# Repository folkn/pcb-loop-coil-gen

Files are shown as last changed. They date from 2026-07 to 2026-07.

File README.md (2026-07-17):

# pcb-loop-coil-gen

Generates a parametric, multi-segment, capacitor-loaded loop-antenna PCB in KiCad — entirely
through the KiCad IPC API ([kicad-python](https://gitlab.com/kicad/code/kicad-python) / `kipy`).
PCB editor only; no schematic is involved.

It draws a ring of copper trace segments around a large center hole, bridges the gaps between
segments with parallel capacitor sets, and feeds the loop through an edge-mount SMA connector.
The board outline is a donut with a rectangular tab at the feed that borders the SMA connector.

## Requirements

- KiCad 10.x with the IPC API server enabled (Preferences > Plugins > Enable KiCad API)
- Python 3.9+ and [kicad-python](https://gitlab.com/kicad/code/kicad-python) built against your
  KiCad install (see kicad-python's own `COMPILING.md`)
- The four footprints under `libraries/` are already included (`.kicad_mod` files) — two custom
  hand-made parts, a Knowles part, and KiCad's stock trimmer capacitor copied out locally

## Usage

1. Open `project/loop_coil.kicad_pcb` in KiCad's PCB editor (or any blank `.kicad_pcb`), with the
   IPC API server running.
2. Edit the parameters at the top of `generate_loop_coil.py` (hole diameter, trace width, number
   of segments, which capacitors to place, SMA orientation, etc).
3. Run it against the open board:
   ```sh
   python generate_loop_coil.py
   ```
   This edits the currently open board in place as a single undo step. It does not save the file
   itself — save from the GUI (Ctrl+S) or call `board.save()` yourself.

If re-running against a board that already has a previous generation on it, clear it first:
```python
from kipy import KiCad
board = KiCad().get_board()
board.remove_items(list(board.get_footprints()) + list(board.get_tracks()) + list(board.get_shapes()))
```

## Topology

The loop is a circle of N trace segments and N gaps, evenly distributed by angle. One gap is the
"feed" gap and contains the SMA connector; the other N-1 gaps each carry a user-chosen, identical
set of parallel capacitors bridging the two neighbouring segments.

At the feed gap: `coilLeft -- FEED_CAP_LEFT -- centerpad -- FEED_CAP_RIGHT -- coilRight`.
`coilRight` is tied directly (copper, no capacitor) to the SMA ground pads; `centerpad` drops
straight down to the SMA center pin. One segment therefore shares the GND net with the SMA ground
pads, while every other segment gets its own unique net (isolated by the capacitor gaps on both
sides).

See the module docstring in `generate_loop_coil.py` for the full picture, and `HANDOFF.md` for
implementation notes, environment quirks, and known simplifications (worth reading before making
nontrivial changes).

## Layout

```
generate_loop_coil.py   - the generator script; all user parameters are at the top
footprint_loader.py     - generic .kicad_mod parser + FootprintInstance builder (see HANDOFF.md
                          for why this exists: the IPC API has no "load footprint by name" call)
libraries/              - the .kicad_mod footprints this project uses
project/                - the KiCad project + board file
HANDOFF.md              - developer notes: environment setup, verification method, design
                          decisions and the reasoning behind them, known limitations
```

## Verifying changes

Don't trust low-resolution renders for fine detail — small parts placed a fraction of a
millimeter apart can look merged. Ground truth is the API: query `board.get_nets()` and each
footprint's `[(pad.number, pad.net.name) for pad in fp.definition.pads]` to check wiring, and pull
exact coordinates to check geometry (see `HANDOFF.md` for the matplotlib-based technique used
during development). For a quick visual check, `kicad-cli pcb export svg` works well.

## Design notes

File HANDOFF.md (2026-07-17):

# Handoff: parametric loop-coil antenna PCB generator

## What this is

A script that builds a multi-segment, capacitor-loaded loop-antenna PCB entirely through the
KiCad IPC API (kicad-python / `kipy`) — PCB editor only, no schematic. It draws a ring of trace
segments around a large center hole, bridges the gaps between segments with parallel capacitor
sets, and feeds the loop through an edge-mount SMA connector at the bottom.

Read `generate_loop_coil.py`'s module docstring first — it describes the net topology (which
segment is which net, how the feed gap's two capacitors and "centerpad" work, why one segment
shares the GND net). This document is about environment/process, not re-explaining that.

## Directory layout

```
/home/folkn/folk-shared/kicad-coil/
├── generate_loop_coil.py   # the generator script -- all user parameters are at the top
├── footprint_loader.py     # generic .kicad_mod parser + FootprintInstance builder (see below)
├── libraries/              # the 4 footprints this project uses, as flat .kicad_mod files
│   ├── CAP_1111B-hand.kicad_mod
│   ├── CAP_Knowles_47273.kicad_mod
│   ├── C_Trimmer_Voltronics_JZ.kicad_mod   # copied out of KiCad's stock Capacitor_SMD.pretty
│   └── SMA_J669.kicad_mod
├── project/
│   └── loop_coil.kicad_pcb # the actual board; this is what the script edits and what you open
├── kicad-python/           # upstream kicad-python repo, cloned + built here (has its own venv)
│   └── .env/               # the venv -- always run scripts through kicad-python/.env/bin/python
└── backups/<timestamp>/    # snapshots of generate_loop_coil.py + footprint_loader.py taken
                             # before risky edits -- there is no git repo here, so this is the
                             # only history; make a new timestamped one before a nontrivial change
```

## Why `footprint_loader.py` exists

The KiCad IPC API (as shipped in this kicad-python / KiCad 10.0.4) has **no RPC to instantiate a
footprint from a library by name** — it only lets a client create raw board items (pads, graphic
shapes, tracks, footprint definitions built from scratch). `footprint_loader.py` works around this
by parsing a `.kicad_mod` S-expression file directly and rebuilding it as a `FootprintInstance`
made of `Pad` / `BoardSegment` / `BoardArc` / `BoardCircle` / `BoardRectangle` items.

This was verified empirically against the live API (not just derived on paper) — see "How to
verify changes" below for the method, which is worth reusing if you touch this file.

Key functions:
- `load_footprint(path) -> FootprintTemplate`: parses pads (front-copper only — back-side pad
  copies are dropped, since this project is top-layer-only) and cosmetic front graphics
  (silkscreen/fab/courtyard).
- `instantiate_footprint(template, position_mm, rotation_deg, reference, net_by_pad=...)`: builds
  the `FootprintInstance`. Pads/graphics are added at their *local* (file) coordinates, then
  placed via `inst.position = ...` followed by `inst.orientation = Angle.from_degrees(...)` — in
  that order, because `FootprintInstance.orientation`'s setter rotates all children about
  `self.position`, so position must already be final before rotating.
- `global_pad_position(...)` / `world_bbox_corners(...)`: pure-Python reimplementations of kipy's
  own rotation formula (`Vector2.rotate`, confirmed by reading `kipy/geometry.py`), used so the
  main script can precompute exact pad/track endpoints without round-tripping to the server.

**Rotation convention** (this tripped me up once — re-derive from the same source rather than
guessing if something looks flipped): kipy's `Vector2.rotate(angle, center)` uses
`new_x = y*sin(a) + x*cos(a); new_y = y*cos(a) - x*sin(a)`. Working through this, a footprint
orientation of `φ` maps a *local* direction at angle `L` (0=local+X, measured the same way as the
`polar()` helper: 0=+X, 90=+Y, ...) to *global* angle `L - φ`. The script's
`orientation_pointing_local_dir(local_dir_deg, target_theta_deg)` helper wraps the inverse of
that (`(local_dir_deg - target_theta_deg) % 360`) — use it rather than hand-deriving angles again.

## Environment / how to run it

KiCad 10.0.4 is installed as an AppImage at `~/Downloads/kicad-10.0.4-x86_64.AppImage`. It is a
"sharun"-wrapped AppImage, **not** a normal one — you must pass an explicit subcommand as the
first argument, e.g. `<appimage> pcbnew <file>` or `<appimage> kicad <file>` (bare
`<appimage> <file>` fails with "Failed to check ELF class").

Important discovery: the plain `kicad` (project-manager) binary, even given a `.kicad_pcb` path
directly, does **not** register the IPC API's board-editing command handlers
(`GetOpenDocuments` etc. fail with "no handler available") unless a PCB editor frame is actually
open. Launching the **standalone `pcbnew` binary** directly with the file as an argument does
work reliably:

```sh
/home/folkn/Downloads/kicad-10.0.4-x86_64.AppImage pcbnew /home/folkn/folk-shared/kicad-coil/project/loop_coil.kicad_pcb &
```

The API server must be enabled (Preferences > Plugins > Enable KiCad API, or set
`"api": {"enable_server": true, ...}` in `~/.config/kicad/10.0/kicad_common.json` and restart —
this was off by default). Once running, the socket appears at `/tmp/kicad/api.sock` and
`kipy.KiCad()` connects to it with no arguments.

To run the generator:
```sh
cd /home/folkn/folk-shared/kicad-coil
kicad-python/.env/bin/python generate_loop_coil.py
```
It edits the currently-open board in place (wrapped in a single `begin_commit`/`push_commit`, so
it's one undo step). It does **not** call `board.save()` itself — call that separately (see
below) or use Ctrl+S in the GUI if you have a display attached.

If you re-run the script against a board that already has a previous generation on it, **clear it
first** or you'll get a duplicate coil on top of the old one:
```python
from kipy import KiCad
board = KiCad().get_board()
board.remove_items(list(board.get_footprints()) + list(board.get_tracks()) + list(board.get_shapes()))
```

## How to verify changes

Don't trust low-res SVG renders for small parts — I initially misread the render and thought the
`TRIMMER` capacitor wasn't being placed in parallel gaps, when in fact it was; the two parts (a
1111B and a much smaller trimmer) sit only ~0.6 mm apart edge-to-edge and merge into what looks
like one blob at typical zoom/export resolutions. Ground truth is always the API, not the image.
Two techniques that worked well together:

1. **Topology / connectivity**: query `board.get_nets()` and, for each footprint,
   `[(p.number, p.net.name) for p in fp.definition.pads]`. Compare against the expected net
   assignments in the module docstring. This catches wiring bugs immediately and is cheap.
2. **Geometry**: for anything spatial (are two parts actually separated, does a rotation point the
   right way), pull exact coordinates from the API and plot them yourself with matplotlib
   (`kicad-python/.env/bin/pip install matplotlib numpy` if not already present) — plot tracks as
   lines, pads as rectangles annotated with `f"{ref}.{pad.number}"`, using `to_mm()` throughout.
   This sidesteps all SVG-scale-guessing and rendering-resolution ambiguity and was what caught
   that the earlier visual read was wrong.

If you do want a quick visual sanity check anyway: `kicad-cli` works standalone (doesn't need the
IPC session), and is more reliable than the API's own `export_svg`/`export_render` (those failed
with "no handler available" when run against the standalone-`pcbnew`-opened document — job-export
RPCs seem to need the full `kicad` app process, not standalone `pcbnew`):
```sh
/tmp/.mount_kicad*/bin/kicad-cli pcb export svg --layers "F.Cu,F.SilkS,Edge.Cuts" \
  --output preview.svg project/loop_coil.kicad_pcb
```
(`librsvg2-bin`'s `rsvg-convert` is installed and can turn that into a PNG for viewing.) The
`/tmp/.mount_kicad*` path is an ephemeral AppImage FUSE mount that only exists while some AppImage
process is running — glob for it fresh each time, don't hardcode the suffix.

## Current parameters / design choices worth knowing about

- Default capacitor set per non-feed gap is now `["CAP_1111B", "TRIMMER"]` — both in parallel,
  stacked radially (pitch = larger of the two footprints' bbox depth + `CAP_STACK_CLEARANCE_MM`).
  Order in the list = innermost to outermost.
- `SMA_CABLE_FLIP_DEG` (default 180) is applied on top of the SMA's base "points away from the
  coil" orientation — it's a named, adjustable offset rather than a hardcoded angle, precisely so
  a future flip request doesn't require re-deriving the rotation math.
- The board outline is a donut: `BOARD_ANNULUS_WIDTH_MM` (default 5 mm) sets the radial distance
  from the raw hole edge to the outer Edge.Cuts boundary, and a tab at the feed gap covers the SMA
  connector down to the GND strap. The outer boundary is **one continuous closed loop, not two
  overlapping closed shapes** — an earlier version drew a full `BoardCircle` plus a
  separately-closed `BoardPolygon` rectangle and relied on KiCad to reconcile the overlap, which is
  the wrong way to add a tab to a board edge. The current version instead: computes where the
  tab's two side walls (straight lines running radially, at constant tangential offset) cross the
  outer circle, replaces that small arc of the circle with three `BoardSegment` lines (side wall,
  tab outer edge, side wall), and represents the remaining major arc as two `BoardArc`s split at
  the point opposite the feed. All of this is built in (radial, tangential) coordinates about
  `theta_feed`, so it stays correct if `FEED_ANGLE_DEG` is ever changed away from the default 90°
  (straight down). Verified by pulling the exact start/end coordinates of every edge shape via the
  API and confirming consecutive endpoints coincide to sub-micron precision (see "How to verify
  changes").
- The tab's outer edge is anchored to `gnd_strap_outer_edge_radius_mm` (the GND strap's far copper
  edge), **not** the SMA's full mechanical bounding box — the part of the connector beyond the
  strap (it's an edge-mount part) is expected to hang off the board. Get this radius via the
  *radial projection* of a strap endpoint onto `radial_unit`, not `math.hypot(...)` distance from
  center — the strap endpoints also carry a tangential offset (they're either side of the center
  pin), so a plain distance overshoots by however much that tangential offset contributes (this
  was an actual bug caught mid-session: `math.hypot(...)` put the tab ~0.2 mm further out than
  intended). If the tab position ever looks off by a small amount again, suspect this class of
  mistake first.
- `HOLE_TRACE_CLEARANCE_MM` (default 0.5 mm) keeps the coil trace's inner copper edge strictly
  outside the raw hole radius. This is *not* sufficient on its own for capacitors, though: a
  capacitor centered on `coil_radius_mm` clips the hole if its radial half-height exceeds
  `TRACE_WIDTH_MM/2` (true for both CAP_1111B and the trimmer at the current trace width). Every
  capacitor placement (feed caps and each generic-gap stack) is therefore anchored so its
  *innermost* body's inner edge lands exactly at the trace's own inner edge
  (`coil_radius_mm - TRACE_WIDTH_MM/2`) rather than being centered on `coil_radius_mm` — see
  `base_radial_offset` in the generic-gap loop and `feed_left_radial_offset`/
  `feed_right_radial_offset` for the feed caps. This is a real geometric proof, not a tuned
  constant: reducing `HOLE_DIAMETER_CM` alone cannot fix hole-clipping, because `coil_radius_mm`
  is defined as `hole_radius_mm + constant`, so the offset between a capacitor's reach and the
  hole edge is invariant to hole size. If clipping ever reappears, look for a capacitor placement
  that bypassed this anchoring, not a hole-size tweak.
- `BOARD_ANNULUS_WIDTH_MM = 5` is tight enough that the outer-stacked capacitor (whichever is last
  in `GAP_CAPACITORS`) currently pokes past the outer boundary — the script's own
  `max_extent_mm > outer_radius_mm` warning fires for this at the current defaults. This is
  expected/known, not a bug: the annulus width and the capacitor stack were set independently per
  explicit request. If it needs to actually fit inside the outer circle, either widen
  `BOARD_ANNULUS_WIDTH_MM` back up or reduce `GAP_CAPACITORS` to fewer/smaller parts.
- The GND strap between the two SMA ground pads is routed by offsetting each pad *radially
  outward* (away from the coil) before joining them, rather than a hardcoded-axis L-route — this
  keeps it correct regardless of `FEED_ANGLE_DEG` or `SMA_CABLE_FLIP_DEG`.

## Known simplifications / good next steps

- The feed-tab's SMA bounding box uses the footprint's parsed local bbox (pads + courtyard
  graphics). If you swap in a different SMA footprint whose courtyard doesn't tightly represent
  its true mechanical edge, the tab will still hug whatever the courtyard says — worth eyeballing
  after a footprint swap.
- Solder-mask margin / thermal-relief overrides on the source footprints (e.g. the Knowles part's
  `solder_mask_margin`, `thermal_bridge_angle`) are not replicated by `footprint_loader.py` —
  cosmetic/manufacturing fine-tuning only, not required for the topology to be correct, but a
  fabrication-readiness pass should double check these.
- `NUM_SEGMENTS == 1` is handled (no generic gaps, single segment = GND net throughout, feed caps
  both still present) but is an unusual/untested-visually edge case — sanity check it if it
  becomes relevant.
- No DRC pass is run by the script. Given the tight default clearances (e.g. the two feed
  capacitors are only `FEED_CENTER_GAP_MM` apart, `STUB_LENGTH_MM` stubs), it'd be worth running
  KiCad's DRC (via the GUI, or look for an API path) before fabrication, especially after
  changing trace width / capacitor choices.

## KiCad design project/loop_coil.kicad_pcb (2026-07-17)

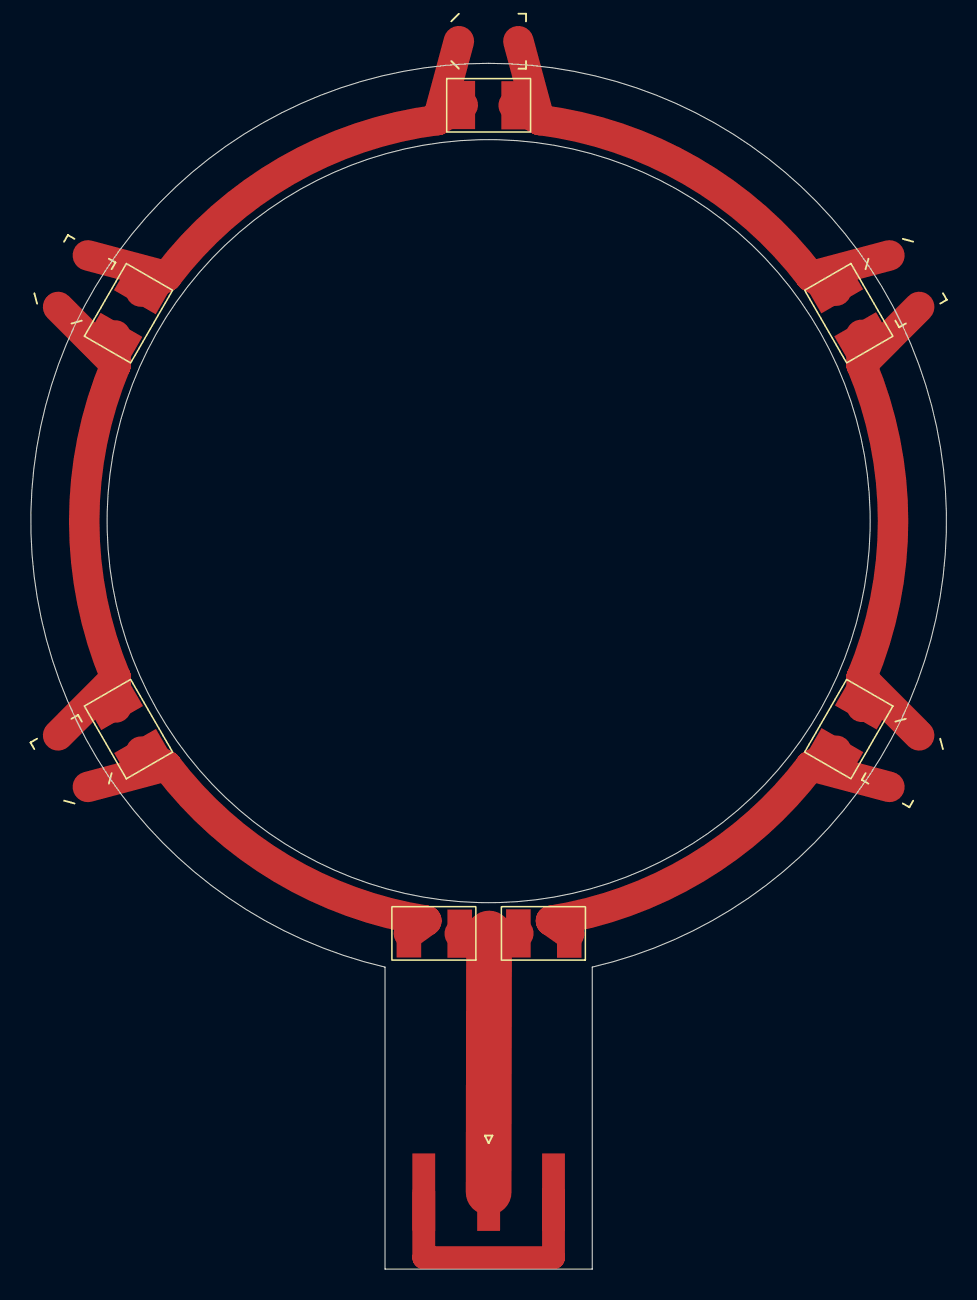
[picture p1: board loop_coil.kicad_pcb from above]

Board: 2 copper layers, 60.0 x 79.0 mm, 13 parts (0 on the bottom side), 7 nets.

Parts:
C1, C3, C5, C7, C9, C11, C12: CAP_1111B-hand
C2, C4, C6, C8, C10: C_Trimmer_Voltronics_JZ
J1: SMA_Amphenol_132289_EdgeMount

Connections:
FEED: C11.1, C12.2, J1.1
GND: C9.2, C10.2, C12.1, J1.2
SEG_1: C1.1, C2.1, C11.2
SEG_2: C1.2, C2.2, C3.1, C4.1
SEG_3: C3.2, C4.2, C5.1, C6.1
SEG_4: C5.2, C6.2, C7.1, C8.1
SEG_5: C7.2, C8.2, C9.1, C10.1
